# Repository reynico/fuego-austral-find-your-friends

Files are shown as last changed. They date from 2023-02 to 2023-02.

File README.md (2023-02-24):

# Find your friends

Each `ESP01` board has a preprogrammed color that defines the person. Each board needs to be preprogrammed with the color you want it to send to other devices. When you sit next to another person, that person's board will fade with the color of your board, and your board will fade with the color of the other person.

## Code
The values from the array define the PWM values for R, G, and B channels, and last it defines the fade effect speed:

```c
const int personValues[] = { 255, 100, 0, 30 };
```

The board is prepared to be used with common anode RGB LEDs, if you're willing to use common cathode LEDs, just comment out the following definition:

```c
#define COMMON_ANODE
```

The code is prepared to be debugged with an ESP8266 board that already has a USB port, just comment out the following definitions:

```c
#define ESP01
#define DEBUG
```
Mind that on the `ESP01` board, the RX and TX pins are used as GPIO outputs to drive the led so it's mandatory to comment out the `DEBUG` define to get the three outputs working.

## Electronics

The pinout arrangement was done in a way that simplifies the wiring procedure. Both boards are glued together near their pin holes, the battery is glued back on both boards and the RGB LED sits over the `ESP01` board, pointing to the WiFi antenna.

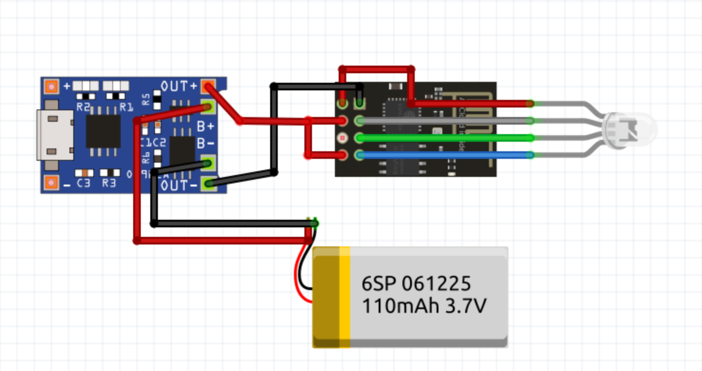
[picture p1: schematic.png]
Board schematic


## Case

The case is a pentagon in form of a jewel, the [top](pendant-top.stl) part stores the boards, led, and battery and the [bottom](pendant-bottom.stl) one is just a cap to make it look nice.

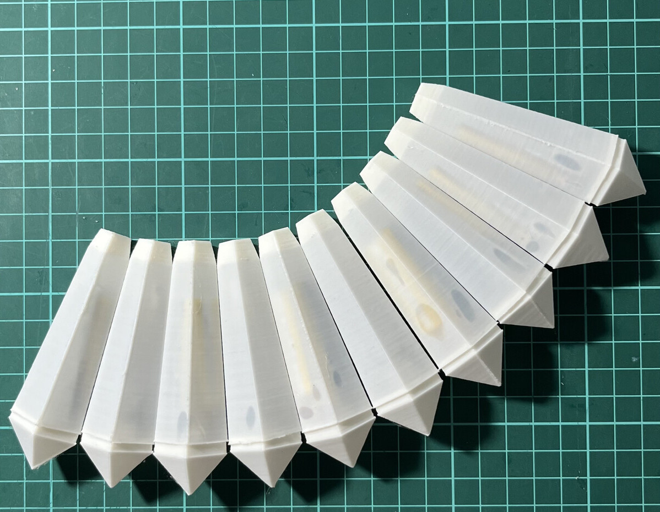
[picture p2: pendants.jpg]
Pendants


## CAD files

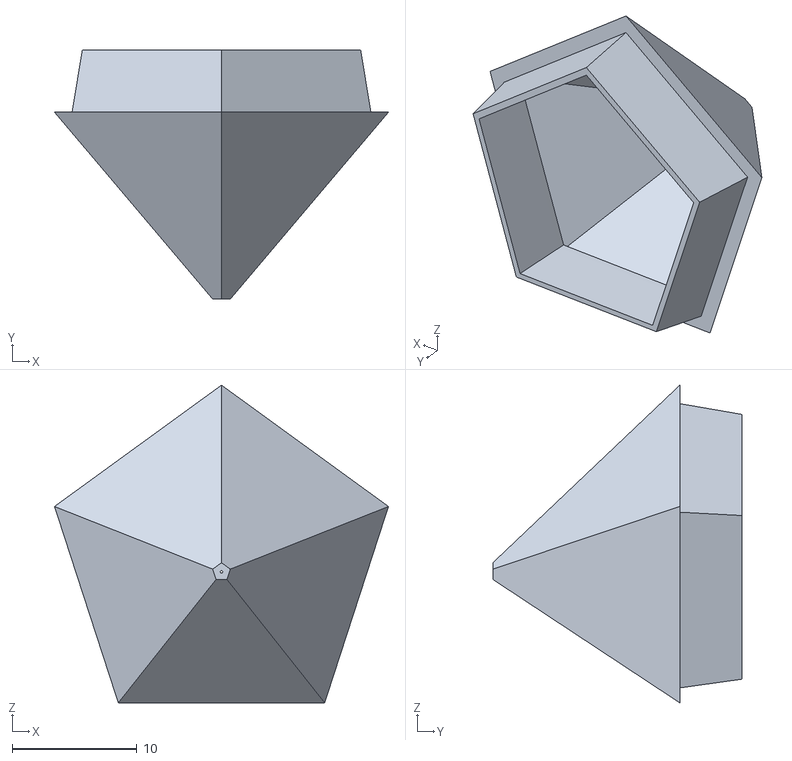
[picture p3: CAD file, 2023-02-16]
pendant-bottom.stl
26.8 x 20.0 x 25.5

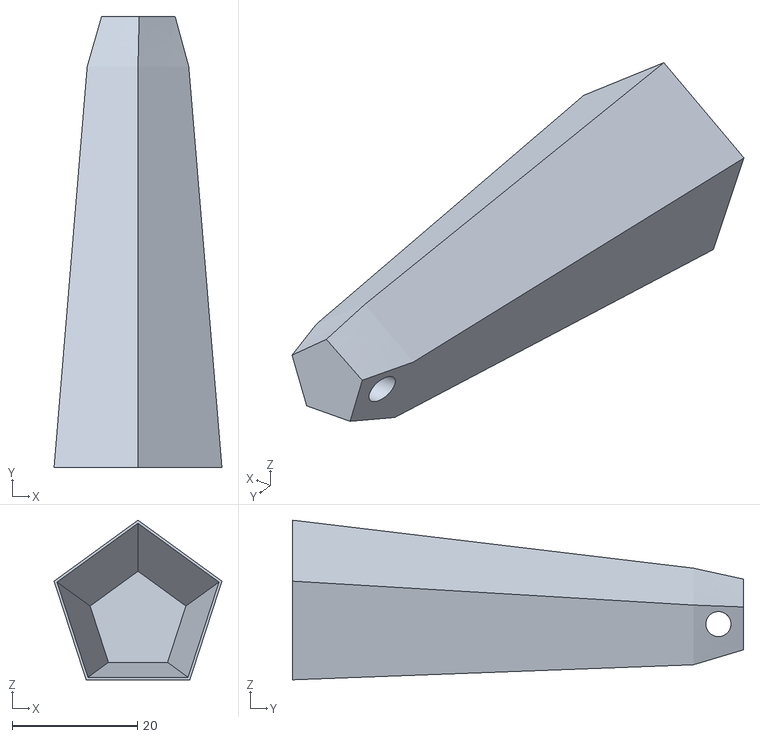
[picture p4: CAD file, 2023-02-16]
pendant-top.stl
26.8 x 72.0 x 25.5

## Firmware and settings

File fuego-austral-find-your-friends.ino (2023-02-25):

#include <ESP8266WiFi.h>
#include <espnow.h>

#define COMMON_ANODE
// #define DEBUG
#define ESP01

// const int personValues[] = { 255, 0,    0,    30 }; // 1
// const int personValues[] = { 255, 255,  0,    30 }; // 2
// const int personValues[] = { 255, 255,  255,  30 }; // 3

const int personValues[] = { 255, 100,    0,    30 }; // 4
// const int personValues[] = { 255, 0,    255,  30 }; // 5
// const int personValues[] = { 0  , 255,  0,    30 }; // 6

// const int personValues[] = { 0  , 255,  255,  30 }; // 7 Day
// const int personValues[] = { 0  , 0,    255,  30 }; // 8
// const int personValues[] = { 50 , 255,  255,  30 }; // 9

// const int personValues[] = { 255, 210,  20 ,  30 }; // 10


#ifdef ESP01
  int ledpins[] = { 1, 0, 3 };
  int anodePin = 2;
#else
  int ledpins[] = { 13, 10, 15 };
  int anodePin = 2;
#endif

uint8_t broadcastAddress[] = { 0xFF, 0xFF, 0xFF, 0xFF, 0xFF, 0xFF };

// Define variables to store incoming readings
int incomingRed;
int incomingBlue;
int incomingGreen;
int incomingSpeed;
int common = 0;
int anode = 0;
int maxAnode = 230;
int minAnode = 50;

// Define variables for control loops
int receiverCounter = 0;
int lastReceiverCounter = 0;
bool off = false;
bool fadeEnabled = false;
bool fadeDisableStatusUpdated = false;
int checksum = 0;
int previousChecksum = 0;
unsigned long previousMillis = 0;

// Update readings every 1 second
const long interval = 1000;

// Define initial led behavior
int values[] = { 0, 0, 0 };
int maxPwmValue[] = { 0, 0, 0 };
int direction[] = { 1, 1, 1 };
int fadeAmount = 30;

// Define WiFi TX power. Values go between 0 and 20.5 dBm
int wifiPower = 0;

// Structure to send data
// Must match the receiver structure
typedef struct struct_message {
  int red;
  int green;
  int blue;
  int speed;
} struct_message;

// Create a struct_message called PersonReadings to hold readings
struct_message PersonReadings;

// Create a struct_message to hold incoming readings
struct_message incomingReadings;

// Callback when data is sent
void OnDataSent(uint8_t *mac_addr, uint8_t sendStatus) {
  Serial.print("Last Packet Send Status: ");
  if (sendStatus == 0) {
    Serial.println("Delivery success");
  } else {
    Serial.println("Delivery fail");
  }
}

// Callback when data is received
void OnDataRecv(uint8_t *mac, uint8_t *incomingData, uint8_t len) {
  memcpy(&incomingReadings, incomingData, sizeof(incomingReadings));
  Serial.print("Bytes received: ");
  Serial.println(len);
  incomingRed = incomingReadings.red;
  incomingGreen = incomingReadings.green;
  incomingBlue = incomingReadings.blue;
  incomingSpeed = incomingReadings.speed;

  receiverCounter += 1;
}

int naiveChecksum(int r, int g, int b, int speed) {
  return r * 8 + g * 4 + b * 2 + speed;
}

void setup() {
  WiFi.setOutputPower(wifiPower); // this sets wifi to lowest power

  #ifdef COMMON_ANODE
    common = 255;
  #endif

  pinMode(anodePin, OUTPUT);
  analogWrite(anodePin, 200);

  for (int i = 0; i < 3; i++) {
    pinMode(ledpins[i], OUTPUT);
    analogWrite(ledpins[i], common - personValues[i]);
  }
  delay(1000);

  for (int i = 0; i < 3; i++) {
    analogWrite(ledpins[i], common - 0);
  }
  analogWrite(anodePin, 0);

  #ifdef DEBUG
    #ifndef ESP01
      Serial.begin(115200);
    #endif
  #endif

  Serial.print("ESP Board MAC Address:  ");
  Serial.println(WiFi.macAddress());

  WiFi.mode(WIFI_STA);
  WiFi.disconnect();

  if (esp_now_init() != 0) {
    Serial.println("Error initializing ESP-NOW");
    return;
  }

  esp_now_set_self_role(ESP_NOW_ROLE_COMBO);

  // Once ESPNow is successfully Init, we will register for Send CB to
  // get the status of Trasnmitted packet
  esp_now_register_send_cb(OnDataSent);

  // Register peer
  esp_now_add_peer(broadcastAddress, ESP_NOW_ROLE_COMBO, 1, NULL, 0);

  // Register for a callback function that will be called when data is received
  esp_now_register_recv_cb(OnDataRecv);
}

void loop() {
  unsigned long currentMillis = millis();
  if (currentMillis - previousMillis >= interval) {
    previousMillis = currentMillis;

    PersonReadings.red = personValues[0];
    PersonReadings.blue = personValues[1];
    PersonReadings.green = personValues[2];
    PersonReadings.speed = personValues[3];

    // Send message via ESP-NOW
    esp_now_send(broadcastAddress, (uint8_t *)&PersonReadings, sizeof(PersonReadings));

    checksum = naiveChecksum(incomingRed, incomingGreen, incomingBlue, incomingSpeed);

    Serial.print("R: ");
    Serial.print(incomingRed);
    Serial.print(" G: ");
    Serial.print(incomingGreen);
    Serial.print(" B: ");
    Serial.print(incomingBlue);
    Serial.print(" speed: ");
    Serial.print(incomingSpeed);
    Serial.print(" counter: ");
    Serial.print(receiverCounter);
    Serial.print(" last: ");
    Serial.print(lastReceiverCounter);
    Serial.print(" checksum: ");
    Serial.println(checksum);

    if (checksum != 0 && receiverCounter > lastReceiverCounter) {
      lastReceiverCounter = receiverCounter;
      fadeEnabled = true;
      if (checksum != previousChecksum) {
        previousChecksum = checksum;
        Serial.print("New checksum detected: ");
        Serial.println(checksum);
        maxPwmValue[0] = incomingRed;
        maxPwmValue[1] = incomingGreen;
        maxPwmValue[2] = incomingBlue;
      }
    } else {
      fadeEnabled = false;
      fadeDisableStatusUpdated = false;
    }
  }

  if (fadeEnabled) {
    analogWrite(ledpins[0], common - maxPwmValue[0]);
    analogWrite(ledpins[1], common - maxPwmValue[1]);
    analogWrite(ledpins[2], common - maxPwmValue[2]);

    for (int i = 0; i < 3; i++) {
      anode = anode + (fadeAmount * direction[i]);
      if (anode <= minAnode || anode >= maxAnode) {
        direction[i] = -direction[i];
      }
      if (anode >= maxAnode) {
        anode = maxAnode;
      }
      if (anode <= minAnode) {
        anode = minAnode;
      }
      analogWrite(anodePin, anode);
      delay(incomingSpeed);
    }
  } else {
    if (!fadeDisableStatusUpdated) {
      fadeDisableStatusUpdated = true;
      Serial.println("off");
      for (int i = 0; i < 3; i++) {
        analogWrite(ledpins[i], common - 0);
      }
    }
  }
}

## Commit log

2023-02-14 disable debug, add toggle for boards
2023-02-16 add schematic
2023-02-16 add readme, add stl files for case
    [pendant-bottom.stl, pendant-top.stl]
2023-02-16 force not to be able to debug over ESP01 boards so RX/TX pins are not interfered with the GPIO outputs
2023-02-24 lint arduino file
2023-02-25 set wifi power, add mac address output for debugging purposes
2023-02-25 move initial led behavior block around functions, define wifi power with a variable
